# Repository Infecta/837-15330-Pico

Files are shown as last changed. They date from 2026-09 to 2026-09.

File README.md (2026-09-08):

# slidrr-PSoC
An attempt at a recreation of the official CHUNITHM Ground Slider for home use.

This project aims to use the same hardware* and firmware of the real ground slider for a more accurate and _faithful_ recreation of CHUNITHM's ground slider input.

<sub>*Same PSoCs. LED driver, power management and other things are ignored.</sub>

**Why?**
---
It all started because I couldn't get a _thick_ (3mm) acrylic overlay working on my original [simpl-slidrr](https://github.com/infecta/simpl-slidrr) project simply due to the fact that the MPR121s perform badly on any overlay above 2mm in thickness.

With this project, since we are using the same PSoCs as the official ground slider it gives us the following benefits:

- As close as possible touch polling/scanning to match arcade
- Thick overlays work reliably (Tested with loose/unscrewed 3mm and 6mm briefly)
- No guesswork needed for psoc firmware

**What this project includes**
---
- KiCad Source Files for the PCB
- CAD Files for the case including the Fusion360 project
- Firmware for the RP2040 Zero

> [!WARNING]
>
> **Agentic AI usage disclosure**
>
> A huge chunk of the code was provided by an AI agent. This only applies to the firmware for the RP2040 Zero.
>
> You may experience weird issues, whacky edge cases that might happen.

**Hardware Architecture**
---
The main CY8C22345 communicates to the RP2040 through UART. The firmware will pass those commands transparently unless it's an LED packet in which case, will be parsed by the RP2040 itself to drive the LEDs   

To put it in simple terms, the main job of the RP2040 is a Serial to USB adapter*

<sub>_*If we just gloss over the fact it also does air tower and IO4 emulation_</sub>

```mermaid
graph LR;
CY(Main CY8C22345)
PICO(RP2040)
LEDS(SK6812MINI-E Array)
Q{IS IT AN LED PACKET}

HOST --> PICO
PICO --> Q
Q --> |NO| CY
Q --> |YES|LED(Parse LED Data) --> LEDS

```
<sup>_Very simplified flowchart of what it does._</sup>

## Parts Needed (PCB)
<sub>All SMD components are 0603 unless stated otherwise</sub>
| Item | Quantity | Notes |
|-|-|-|
| CY8C22345 | 2 | [Link(Taobao)](https://item.taobao.com/item.htm?id=972956170652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). Same chips used as the official ground slider. Depending on where you are, these may be easier or harder to source. Must be an SSOP-28 package to fit on the PCB. If you found a different package you'll have modify the PCB. Get extras just in case things go wrong (bad chip, broken pins etc.)
| Arduino Pro Micro | 1 | A cheap (and slightly difficult) way to flash the PSoC with the ground slider firmware using [arduino_hssp](https://github.com/miracoli/arduino_hssp). **Make sure it's the 5V model**. **NOTE: You will need linux to use this with [psocdude](https://github.com/miracoli/psocdude)**. If you have another way of programming the PSoC like a MiniProg then go that route.
| WaveShare RP2040 Zero | 1 | Main brains (UART Passthrough, IO4, LED driver)
| [This](./guide-media/button.png) SMD tactile switch | 2 | I'm not sure what these are formally called. but I used these for the footprint on the PCB.
| SN74LV1T34DBVR Logic Level Shifter | 1 | This is for the SK6812MINI-E LED data pins (Needs 5V logic rather than 3.3V logic). You can substitute this with any other level shifter provided it's pin compatible or modify the PCB if you want to use a different one.
| SK6812MINI-E LEDs | 31 | LEDs.
| 4x DIP switch | 1 | Temporary but needed during flashing & troubleshooting. Mainly to connect both PSoC I<sup>2</sup>C lines and connect to the I<sup>2</sup>C pull-up resistors.
| JST XH5 Connectors | 2 | Optional. But nice to have to reliably flash PSoCs
| JST XH6 Connectors | 2 | For connecting air towers
| 100nf/0.1uF X5R Capacitors | 32 | Decoupling caps for level shifter and LEDs 
| 4.7uF X5R Capacitors | 4 | Decoupling caps for PSoCs
| 4.7nF X7R Capacitors | 2 | CapSense<sup>TM</sup> Modulator cap
| 560R/560ohm Resistors | 32 | Placed before the touch electrodes. Values are just an estimate and typical range I have tested.
| 1K Resistor | 1 | Part of a voltage divider to shift down the 5V UART signal to 3.3V going into the RP2040 Zero
| 2K Resistor | 1 | Part of a voltage divider to shift down the 5V UART signal to 3.3V going into the RP2040 Zero
| 3K - 4.7K Resistor | 2 | I<sup>2</sup>C pull-up resistors. Within this range should be fine.
| 330R/330ohm Resistor | 1 | Needed for the logic level shifter. Followed datasheet. If changing level shifter check datasheet for info.
| [whowechina chu_pico IR airs](https://github.com/whowechina/chu_pico) | 1 pair | IR tower code based around this design. Check chu_pico repo for more info. **IMPORTANT:** CURRENT LIMITING RESISTORS NEED TO BE CHANGED TO A HIGHER VALUE. CHECK BELOW.

## Notes

The chu_pico airs draw around ~878mA per emitter with 0.75ohm resistor (If we were to follow whowe's guide for the airs). Either due to the WaveShare RP2040 zero's 3v3 regulator or general power budget **it is too high** and UART will fail as there is not enough power to go around for the PSoCs and possibly the LEDs.

> [!WARNING]
>
> Using the airs as-is with the 0.75ohm resistors **may** burn out the 3v3 regulator as it can get **very** hot.
> 

I suggest using a 50ohm or 100ohm resistor instead. This drops the emitter amperage draw to about ~40mA and ~21mA respectively.
Peak for a single IR phase (2 IR Emitters) would be ~80mA and ~42mA respectively too, which is well within the budget

## Build _*"guide"*_

This doc fully assumes you are comfortable with soldering SMD components.

_Protip: Use the Interactive Html Bom plugin on KiCAD to easily figure out where all the components go._

### Ordering the PCB
---
We're using [JLCPCB](https://jlcpcb.com) for this guide.

You can leave everything on default but I recommend a black solder mask so that the lights look better

### Notes for the RP2040-Zero
---
I won't lie, I forgot why I even placed the footprint they way I did.
But the RP2040 chip is facing **upwards** so please keep that in mind.

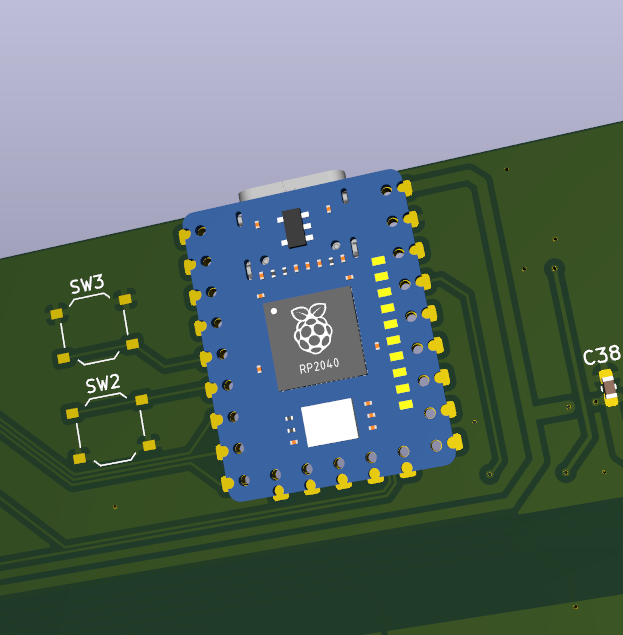
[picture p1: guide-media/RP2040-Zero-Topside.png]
RP2040 TopSide

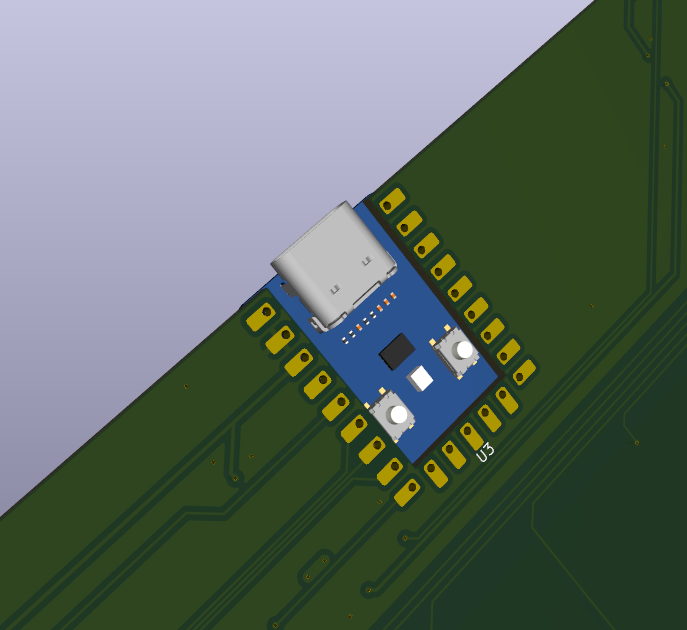
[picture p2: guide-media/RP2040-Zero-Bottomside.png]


### Flashing the firmware
---
**This section will assume you are doing the psocdude + arduino_hssp route.**

**This also assumes you have sourced your own dump of the offical 837-15330/Ground slider firmware**

**This section will not guide you on how to flash the arduino or compile psocdude. Use google or ask an LLM for guidance.**

Few things are needed to change in the `psocdude.conf` file in order to get it flashed.

Inside `psocdude.conf` find the `CY8C22345` line. It should look like this.
```bash
#------------------------------------------------------------
# CY8C22345
#------------------------------------------------------------

part
  id      = "CY8C22345";
  desc    = "CY8C22345";
  signature   = 0x00 0xD1;
  checksum_setup = CHECKSUM_SETUP_22_24_28_29_TST120_TMG120_TMA120;
  program_block = PROGRAM_BLOCK_21_22_23_24_28_29_TST_TMG_TMA;
  multi_bank = yes;
  memory "signature"
    size = 2;
  ;
;
```

Change it so it looks like this:
```bash
#------------------------------------------------------------
# CY8C22345
#------------------------------------------------------------

part
  id      = "CY8C22345";
  desc    = "CY8C22345";
  signature   = 0x00 0xD0;
  checksum_setup = CHECKSUM_SETUP_22_24_28_29_TST120_TMG120_TMA120;
  program_block = PROGRAM_BLOCK_21_22_23_24_28_29_TST_TMG_TMA;
  multi_bank = yes;
  memory "flash"
    paged     = yes;
    size      = 16384;
    page_size = 64;
    num_pages = 256;
    blocksize = 64;
    readsize  = 64;
  ;
  memory "signature"
    size = 2;
  ;
;
```

Flash the PSoC with:
```bash
psocdude -C psocdude.conf -p CY8C22345 -c arduino -P /dev/ttyACM0 -b 115200 -U flash:w:<DUMPED_FIRMWARE.bin/.hex>:r -F
```

#### Troubleshooting
---

**Scenario 1**

If your output looks like this:
```bash
Reading |                     | 0% 0.00spsocdude: ser_recv(): proggrammer is not responding
psocdude: error reading signature data for part "CY8C22345", rc=-1
psocdude: error reading signature data, rc=-1
```

It could be either one of 2 issues:

1. Unplug and replug your programmer, then try running the command again.

2. If that doesn't work check your solder connections.

**Scenario 2**

If your signature is 0xffff
1. Bad soldering.
2. Bad chip. (Unconfirmed)

I haven't figured out why this happens as of writing this. My only solution was switching out the chips with the extras I already had.

There might be more issues that I haven't experienced yet so I can't cover all bases.

### Case
---
TODO: CASE GUIDE HERE

## Credits

[whowechina](https://github.com/whowechina) - Air Code and PCB is heavily referenced and adapted for the firmware from the [chu_pico](https://github.com/whowechina/chu_pico) project.

[Cons&Stuff](https://consandstuff.github.io/) Discord Server - For guidance and troubleshooting of my project especially [somewhatlurker](https://github.com/somewhatlurker) for their insight of the slider protocol.

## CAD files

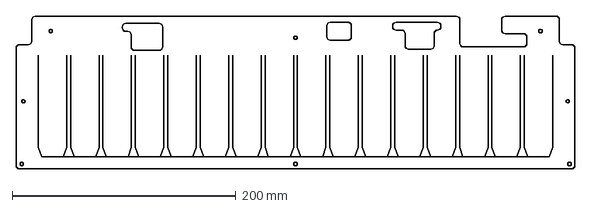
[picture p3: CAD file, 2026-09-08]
Case-files/chu-psoc-lgp-panel.dxf
500.0 x 136.5 mm

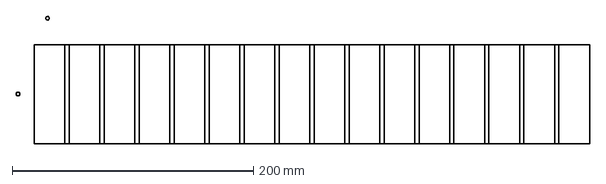
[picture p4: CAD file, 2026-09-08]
KiCAD-project-files/DXF/Isolated/Acrylic Light Guide.dxf
475.3 x 105.4 mm

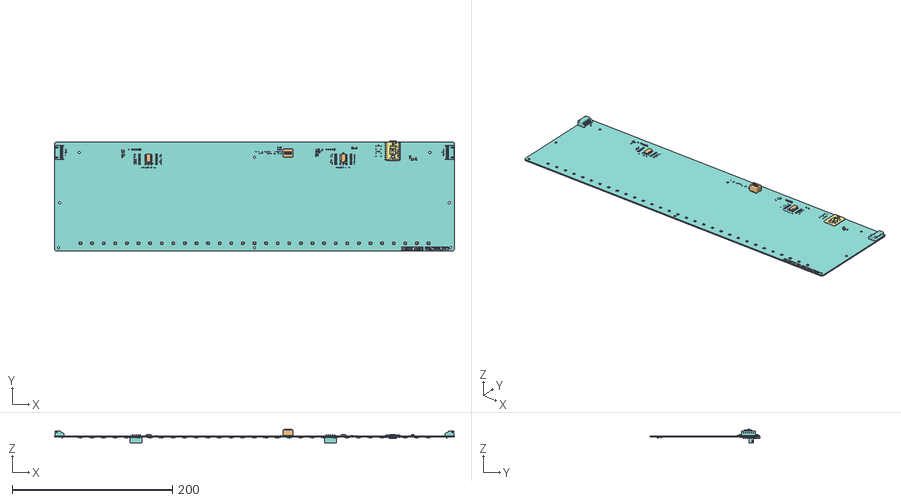
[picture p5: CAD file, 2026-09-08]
KiCAD-project-files/pcb-model/processed-23-08-2026 [1]/slidrr-cy8c.obj
500.0 x 137.7 x 17.3
obj1
obj2
obj3
obj4
obj5
obj6
obj7
obj8
obj9
obj10
obj11
obj12
obj13
obj14
obj15
obj16
obj17
obj18
obj19
obj20
obj21
obj22
obj23
obj24
obj25
obj26
obj27
obj28
obj29
obj30
obj31
obj32

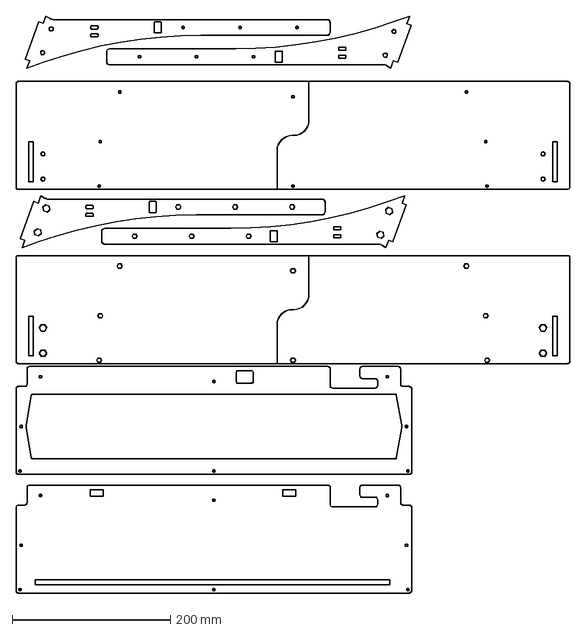
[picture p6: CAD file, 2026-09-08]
Case-files/chu-psoc-casepieces.dxf
700.0 x 729.2 mm

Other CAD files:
KiCAD-project-files/DXF/slidrr-cy8c.dxf
KiCAD-project-files/pcb-model/processed-23-08-2026 [2]/slidrr-cy8c.obj
KiCAD-project-files/pcb-model/processed-23-08-2026/slidrr-cy8c.obj
Case-files/slidrr-housing.f3d

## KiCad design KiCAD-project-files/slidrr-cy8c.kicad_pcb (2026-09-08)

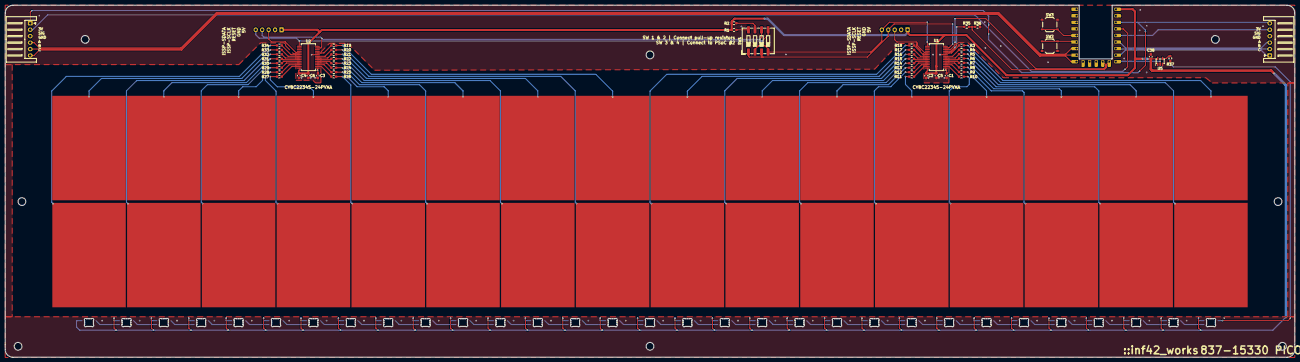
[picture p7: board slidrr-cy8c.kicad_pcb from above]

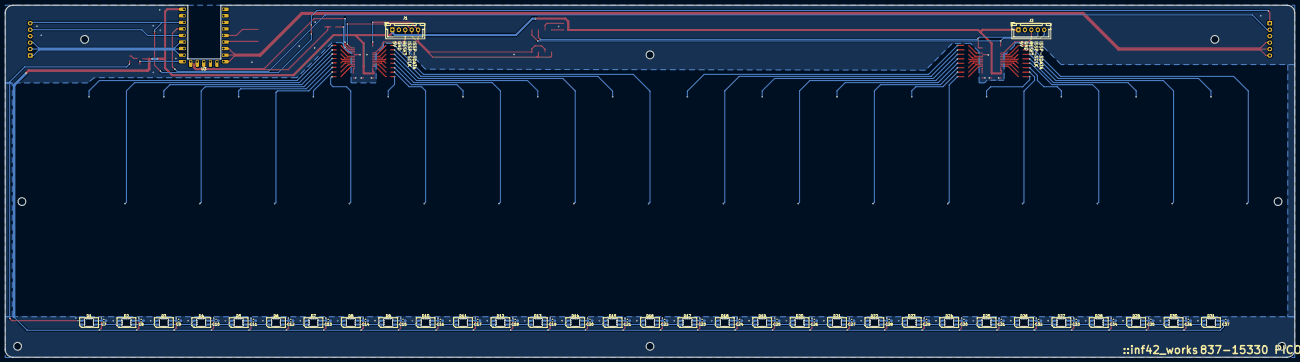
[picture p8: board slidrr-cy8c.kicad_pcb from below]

Board: 2 copper layers, 500.0 x 136.5 mm, 118 parts (65 on the bottom side), 123 nets.

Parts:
C1, C3: 4.7nF X7R; C_0603_1608Metric_Pad1.08x0.95mm_HandSolder
C2, C4, C5, C6: X5R 4.7uF 16V; C_0603_1608Metric_Pad1.08x0.95mm_HandSolder
C7, C8, C9, C10, C11, C12, C13, C14, C15, C16, C17, C18, C19, C20, C21, C22, C23, C24, C25, C26, C27, C28, C29, C30, C31, C32, C33, C34, C35, C36, C37, C38: 0.1uF; C_0603_1608Metric_Pad1.08x0.95mm_HandSolder
D1, D2, D3, D4, D5, D6, D7, D8, D9, D10, D11, D12, D13, D14, D15, D16, D17, D18, D19, D20, D21, D22, D23, D24, D25, D26, D27, D28, D29, D30, D31: SK6812MINI-E; LED_SK6812MINI-E_3.2x2.8mm_P1.5mm_ReverseMount
J1: ISSP U1; JST_XH_B5B-XH-A_1x05_P2.50mm_Vertical
J2: ISSP U2; JST_XH_B5B-XH-A_1x05_P2.50mm_Vertical
J3: Conn_01x32_Socket; slidrr-touchslider
J4, J5: JST-XH Series; JST_XH_S6B-XH-A_1x06_P2.50mm_Horizontal
R1, R2: 3.2K; R_0603_1608Metric_Pad0.98x0.95mm_HandSolder
R3, R4, R5, R6, R7, R8, R9, R10, R11, R12, R13, R14, R15, R16, R17, R18, R19, R20, R21, R22, R23, R24, R25, R26, R27, R28, R29, R30, R31, R32, R33, R34: R_Small; R_0603_1608Metric_Pad0.98x0.95mm_HandSolder
R35: 1K; R_0603_1608Metric_Pad0.98x0.95mm_HandSolder
R36: 2K; R_0603_1608Metric_Pad0.98x0.95mm_HandSolder
R37: 330R; R_0603_1608Metric_Pad0.98x0.95mm_HandSolder
SW1: SW_DIP_x04; SW_DIP_SPSTx04_Slide_9.78x12.34mm_W8.61mm_P2.54mm
SW2, SW3: SW_Push; SW_Push_1P1T_XKB_TS-1187A
U1, U2: SSOP-28_5.3x10.2mm_P0.65mm
U3: RP2040-Zero
U5: SN74LV1T34DBVR; SOT-23-5

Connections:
3V3: J4.1, J5.6, U3.20 (3V3)
3v3 LED DATA: U3.14 (GP14), U5.2 (A)
5V LED DATA: D1.2 (DIN), R37.2
+5V: C2.1, C4.1, C5.1, C6.1, C7.2, C8.2, C9.2, C10.2, C11.2, C12.2, C13.2, C14.2, C15.2, C16.2, C17.2, C18.2, C19.2, C20.2, C21.2, C22.2, C23.2, C24.2, C25.2, C26.2, C27.2, C28.2, C29.2, C30.2, C31.2, C32.2, C33.2, C34.2, C35.2, C36.2, C37.2, C38.2, D1.3 (VDD), D2.3 (VDD), D3.3 (VDD), D4.3 (VDD), D5.3 (VDD), D6.3 (VDD), D7.3 (VDD), D8.3 (VDD), D9.3 (VDD), D10.3 (VDD), D11.3 (VDD), D12.3 (VDD), D13.3 (VDD), D14.3 (VDD), D15.3 (VDD), D16.3 (VDD), D17.3 (VDD), D18.3 (VDD), D19.3 (VDD), D20.3 (VDD), D21.3 (VDD), D22.3 (VDD), D23.3 (VDD), D24.3 (VDD), D25.3 (VDD), D26.3 (VDD), D27.3 (VDD), D28.3 (VDD), D29.3 (VDD), D30.3 (VDD), D31.3 (VDD), J1.1, J2.1, R1.2, R2.2, U1.28 (Vdd), U2.28 (Vdd), U3.22 (5V), U5.5 (VCC)
AIR A L: J4.4, U3.6 (GP6)
AIR A R: J5.3, U3.17 (GP27)
AIR B L: J4.5, U3.7 (GP7)
AIR B R: J5.2, U3.16 (GP26)
AIR C L: J4.6, U3.8 (GP8)
AIR C R: J5.1, U3.15 (GP15)
AIR SIG L: J4.2, U3.19 (GP29)
AIR SIG R: J5.5, U3.18 (GP28)
GND: C1.1, C2.2, C3.1, C4.2, C5.2, C6.2, C7.1, C8.1, C9.1, C10.1, C11.1, C12.1, C13.1, C14.1, C15.1, C16.1, C17.1, C18.1, C19.1, C20.1, C21.1, C22.1, C23.1, C24.1, C25.1, C26.1, C27.1, C28.1, C29.1, C30.1, C31.1, C32.1, C33.1, C34.1, C35.1, C36.1, C37.1, C38.1, D1.1 (VSS), D2.1 (VSS), D3.1 (VSS), D4.1 (VSS), D5.1 (VSS), D6.1 (VSS), D7.1 (VSS), D8.1 (VSS), D9.1 (VSS), D10.1 (VSS), D11.1 (VSS), D12.1 (VSS), D13.1 (VSS), D14.1 (VSS), D15.1 (VSS), D16.1 (VSS), D17.1 (VSS), D18.1 (VSS), D19.1 (VSS), D20.1 (VSS), D21.1 (VSS), D22.1 (VSS), D23.1 (VSS), D24.1 (VSS), D25.1 (VSS), D26.1 (VSS), D27.1 (VSS), D28.1 (VSS), D29.1 (VSS), D30.1 (VSS), D31.1 (VSS), J1.2, J2.2, J4.3, J5.4, R36.2, SW2.2, SW3.2, U1.9 (Vss/GND), U1.14 (Vss/GND), U2.9 (Vss/GND), U2.14 (Vss/GND), U3.21 (GND), U5.3 (GND)
I2C_SCL_U1: J1.4, SW1.1, SW1.3, U1.13 (P1[1])
I2C_SCL_U2: J2.4, SW1.6, U2.13 (P1[1])
I2C_SDA_U1: J1.5, SW1.2, SW1.4, U1.15 (P1[0])
I2C_SDA_U2: J2.5, SW1.5, U2.15 (P1[0])
ISSP_RESET_U1: J1.3, U1.19 (XRES)
ISSP_RESET_U2: J2.3, U2.19 (XRES)
unnamed: D1.4 (DOUT), D2.2 (DIN)
unnamed: D2.4 (DOUT), D3.2 (DIN)
unnamed: D3.4 (DOUT), D4.2 (DIN)
unnamed: D4.4 (DOUT), D5.2 (DIN)
unnamed: D5.4 (DOUT), D6.2 (DIN)
unnamed: D6.4 (DOUT), D7.2 (DIN)
unnamed: D7.4 (DOUT), D8.2 (DIN)
unnamed: D8.4 (DOUT), D9.2 (DIN)
unnamed: D9.4 (DOUT), D10.2 (DIN)
unnamed: D10.4 (DOUT), D11.2 (DIN)
unnamed: D11.4 (DOUT), D12.2 (DIN)
unnamed: D12.4 (DOUT), D13.2 (DIN)
unnamed: D13.4 (DOUT), D14.2 (DIN)
unnamed: D14.4 (DOUT), D15.2 (DIN)
unnamed: D15.4 (DOUT), D16.2 (DIN)
unnamed: D16.4 (DOUT), D17.2 (DIN)
unnamed: D17.4 (DOUT), D18.2 (DIN)
unnamed: D18.4 (DOUT), D19.2 (DIN)
unnamed: D19.4 (DOUT), D20.2 (DIN)
unnamed: D20.4 (DOUT), D21.2 (DIN)
unnamed: D21.4 (DOUT), D22.2 (DIN)
unnamed: D22.4 (DOUT), D23.2 (DIN)
unnamed: D23.4 (DOUT), D24.2 (DIN)
unnamed: D24.4 (DOUT), D25.2 (DIN)
unnamed: D25.4 (DOUT), D26.2 (DIN)
unnamed: D26.4 (DOUT), D27.2 (DIN)
unnamed: D27.4 (DOUT), D28.2 (DIN)
unnamed: D28.4 (DOUT), D29.2 (DIN)
unnamed: D29.4 (DOUT), D30.2 (DIN)
unnamed: D30.4 (DOUT), D31.2 (DIN)
unnamed: J3.1, R3.1
unnamed: J3.2, R4.1
unnamed: J3.3, R5.1
unnamed: J3.4, R6.1
unnamed: J3.5, R7.1
unnamed: J3.6, R8.1
unnamed: J3.7, R9.1
unnamed: J3.8, R10.1
unnamed: J3.9, R11.1
unnamed: J3.10, R12.1
unnamed: J3.11, R13.1
unnamed: J3.12, R14.1
unnamed: J3.13, R15.1
unnamed: J3.14, R16.1
unnamed: J3.15, R17.1
unnamed: J3.16, R18.1
unnamed: J3.17, R19.1
unnamed: J3.18, R20.1
unnamed: J3.19, R21.1
unnamed: J3.20, R22.1
unnamed: J3.21, R23.1
unnamed: J3.22, R24.1
unnamed: J3.23, R25.1
unnamed: J3.24, R26.1
unnamed: J3.25, R27.1
unnamed: J3.26, R28.1
unnamed: J3.27, R29.1
unnamed: J3.28, R30.1
unnamed: J3.29, R31.1
unnamed: J3.30, R32.1
unnamed: J3.31, R33.1
unnamed: J3.32, R34.1
unnamed: R1.1, SW1.8
unnamed: R2.1, SW1.7
unnamed: C1.2, U1.1 (P0[7])
unnamed: C3.2, U2.1 (P0[7])
unnamed: R35.2, R36.1, U3.13 (GP13)
unnamed: R37.1, U5.4 (Y)
SERVICE: SW2.1, U3.5 (GP5)
TEST: SW3.1, U3.4 (GP4)
TOUCH 1: R3.2, U1.10 (P1[7])
TOUCH 2: R4.2, U1.8 (P2[1])
TOUCH 3: R5.2, U1.7 (P2[3])
TOUCH 4: R6.2, U1.6 (P2[5])
TOUCH 5: R7.2, U1.5 (P2[7])
TOUCH 6: R8.2, U1.4 (P0[1])
TOUCH 7: R9.2, U1.3 (P0[3])
TOUCH 8: R10.2, U1.2 (P0[5])
TOUCH 9: R11.2, U1.27 (P0[6])
TOUCH 10: R12.2, U1.26 (P0[4])
TOUCH 11: R13.2, U1.25 (P0[2])
TOUCH 12: R14.2, U1.24 (P0[0])
TOUCH 13: R15.2, U1.23 (P2[6])
TOUCH 14: R16.2, U1.22 (P2[4])
TOUCH 15: R17.2, U1.21 (P2[2])
TOUCH 16: R18.2, U1.20 (P2[0])
TOUCH 17: R19.2, U2.10 (P1[7])
TOUCH 18: R20.2, U2.8 (P2[1])
TOUCH 19: R21.2, U2.7 (P2[3])
TOUCH 20: R22.2, U2.6 (P2[5])
TOUCH 21: R23.2, U2.5 (P2[7])
TOUCH 22: R24.2, U2.4 (P0[1])
TOUCH 23: R25.2, U2.3 (P0[3])
TOUCH 24: R26.2, U2.2 (P0[5])
TOUCH 25: R27.2, U2.27 (P0[6])
TOUCH 26: R28.2, U2.26 (P0[4])
TOUCH 27: R29.2, U2.25 (P0[2])
TOUCH 28: R30.2, U2.24 (P0[0])
TOUCH 29: R31.2, U2.23 (P2[6])
TOUCH 30: R32.2, U2.22 (P2[4])
TOUCH 31: R33.2, U2.21 (P2[2])
TOUCH 32: R34.2, U2.20 (P2[0])
UART_RX_U1: U1.12 (P1[3]), U3.12 (GP12)
UART_TX_U1: R35.1, U1.11 (P1[5])

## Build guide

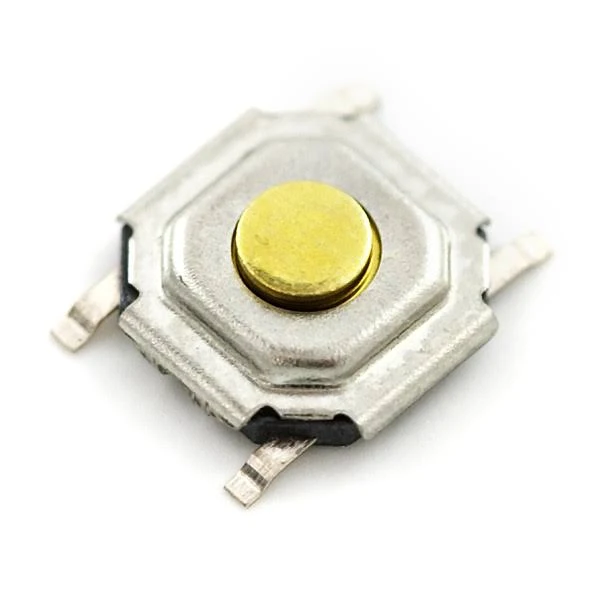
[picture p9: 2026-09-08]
guide-media/button.png

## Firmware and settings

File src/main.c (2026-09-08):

#include <string.h>
#include <stdio.h>
#include "bsp/board.h"
#include "hardware/gpio.h"
#include "pico/multicore.h"
#include "pico/stdlib.h"
#include "tusb.h"
#include "air.h"
#include "calibration.h"
#include "io4.h"
#include "led_driver.h"
#include "uart_bridge.h"
#include "usb_descriptors.h"

#define TEST_PIN 4
#define IO4_REPORT_INTERVAL_MS 4
#define AIR_DIAGNOSTIC_CDC 1
#define AIR_DIAGNOSTIC_INTERVAL_MS 100

static absolute_time_t next_io4_report;
static absolute_time_t next_air_diagnostic;

static io4_state_t io4_state;
static io4_input_report_t io4_report;

static void air_diagnostic_task(void) {
    if (!time_reached(next_air_diagnostic)) {
        return;
    }

    char line[64];
    const int length = snprintf(
        line,
        sizeof(line),
        "%u,%u,%u,%u,%u,%u\r\n",
        (unsigned)air_sensor_raw_value(IO4_AIR_LEFT_A),
        (unsigned)air_sensor_raw_value(IO4_AIR_RIGHT_A),
        (unsigned)air_sensor_raw_value(IO4_AIR_LEFT_B),
        (unsigned)air_sensor_raw_value(IO4_AIR_RIGHT_B),
        (unsigned)air_sensor_raw_value(IO4_AIR_LEFT_C),
        (unsigned)air_sensor_raw_value(IO4_AIR_RIGHT_C)
    );

    if (length <= 0 || (uint32_t)length > sizeof(line) ||
        tud_cdc_n_write_available(AIR_DIAGNOSTIC_CDC) < (uint32_t)length) {
        return;
    }

    (void)tud_cdc_n_write(AIR_DIAGNOSTIC_CDC, line, (uint32_t)length);
    (void)tud_cdc_n_write_flush(AIR_DIAGNOSTIC_CDC);
    next_air_diagnostic =
        make_timeout_time_ms(AIR_DIAGNOSTIC_INTERVAL_MS);
}

static bool calibration_requested(void) {
    gpio_init(TEST_PIN);
    gpio_set_dir(TEST_PIN, GPIO_IN);
    gpio_pull_up(TEST_PIN);

    if (gpio_get(TEST_PIN)) {
        return false;
    }

    sleep_ms(25);
    return !gpio_get(TEST_PIN);
}

static void show_colour_for(uint8_t red,
    uint8_t green,
    uint8_t blue,
    uint32_t duration_ms) {
    led_driver_set_solid(red, green, blue);

    absolute_time_t deadline =
        make_timeout_time_ms(duration_ms);

    while (!time_reached(deadline)) {
        led_driver_task();
        tight_loop_contents();
    }
}

int main(void) {
    uint16_t baselines[IO4_AIR_CHANNEL_COUNT];

    board_init();
    air_sensor_init();
    led_driver_init();

    if (calibration_requested()) {
        /*
         * Continuously scan for two seconds while the towers are clear.
         * This gives every phase repeated opportunities to stabilize.
         */
        led_driver_set_solid(255, 0, 0);
    
        absolute_time_t calibration_end =
            make_timeout_time_ms(2000);
    
        while (!time_reached(calibration_end)) {
            air_sensor_update();
            led_driver_task();
            tight_loop_contents();
        }
    
        if (air_sensor_capture_baselines(baselines) &&
            calibration_save(baselines)) {
            air_sensor_set_baselines(baselines);
    
            /* Green remains until game LED traffic replaces it. */
            led_driver_set_solid(0, 255, 0);
        }
    
        /*
         * Leave the display red when capture or flash saving fails.
         */
    } else if (calibration_load(baselines)) {
        air_sensor_set_baselines(baselines);
    }

    uart_bridge_init();
    io4_init( & io4_state);
    tusb_init();
    next_io4_report = get_absolute_time();
    next_air_diagnostic = get_absolute_time();

    // Flash operations are finished before this starts.
    multicore_launch_core1(air_sensor_core1_entry);

    while (true) {
        tud_task();

        uart_bridge_task();
        led_driver_task();
        air_diagnostic_task();

        io4_set_test_pressed( & io4_state, !gpio_get(TEST_PIN));

        io4_set_air_blocked( &
            io4_state,
            air_sensor_blocked_bitmap()
        );

        if (tud_hid_n_ready(0) && time_reached(next_io4_report)) {
            io4_build_input_report( & io4_state, & io4_report);

            tud_hid_n_report(
                0,
                IO4_REPORT_ID_INPUT, &
                io4_report,
                sizeof(io4_report)
            );

            next_io4_report =
                delayed_by_ms(next_io4_report, IO4_REPORT_INTERVAL_MS);
        }

        tight_loop_contents();
    }
}

uint16_t tud_hid_get_report_cb(uint8_t instance,
    uint8_t report_id,
    hid_report_type_t report_type,
    uint8_t * buffer,
    uint16_t requested_length) {
    (void) instance;

    if (report_id != IO4_REPORT_ID_INPUT ||
        report_type != HID_REPORT_TYPE_INPUT ||
        buffer == NULL) {
        return 0;
    }

    io4_build_input_report( & io4_state, & io4_report);

    uint16_t length = requested_length < sizeof(io4_report) ?
        requested_length :
        sizeof(io4_report);

    memcpy(buffer, & io4_report, length);
    return length;
}

void tud_hid_set_report_cb(uint8_t instance,
    uint8_t report_id,
    hid_report_type_t report_type,
    const uint8_t * buffer,
        uint16_t buffer_size) {
    (void) instance;

    if (report_type != HID_REPORT_TYPE_OUTPUT || buffer == NULL) {
        return;
    }

    const uint8_t * payload = buffer;
    uint16_t payload_size = buffer_size;

    if (report_id == 0) {
        if (buffer_size < 2 ||
            buffer[0] != IO4_REPORT_ID_OUTPUT) {
            return;
        }

        payload = & buffer[1];
        payload_size = buffer_size - 1;
    } else if (report_id != IO4_REPORT_ID_OUTPUT) {
        return;
    }

    io4_process_command( &
        io4_state,
        payload,
        payload_size
    );
}

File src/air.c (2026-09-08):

#include "air.h"

#include <stdbool.h>
#include <stdint.h>
#include <string.h>

#include "hardware/adc.h"
#include "hardware/gpio.h"
#include "pico/stdlib.h"

#define IR_PHASES 3

// ADC GPIO Assignments
// If you're changing this, change IR_SIGNAL_ADC too.
#define ADC_LEFT 29
#define ADC_RIGHT 28

// IR Phase Pin Assignments for each side
// Goes like { A, B, C }
static const uint8_t IR_LEFT_CHANNEL[IR_PHASES] = { 6, 7, 8 };

static const uint8_t IR_RIGHT_CHANNEL[IR_PHASES] = { 27, 26, 15 };

// ADC Pin Assignments
// GP29 = ADC3 = left signal
// GP28 = ADC2 = right signal
static const uint8_t IR_SIGNAL_ADC[2] = { 3, 2 };

static volatile uint16_t ir_raw[IO4_AIR_CHANNEL_COUNT];
static bool ir_blocked[IO4_AIR_CHANNEL_COUNT];

static uint16_t ir_baselines[IO4_AIR_CHANNEL_COUNT] = {
    3800, 3800,
    3800, 3800,
    3800, 3800,
};

static const uint8_t IR_TRIGGER_PERCENT = 17;

#define IR_DEBOUNCE_PERCENT 90

static uint8_t current_phase;
static volatile uint8_t published_bitmap;

static void emitters_off(void)
{
    for (uint8_t phase = 0; phase < IR_PHASES; ++phase) {
        gpio_put(IR_LEFT_CHANNEL[phase], false);
        gpio_put(IR_RIGHT_CHANNEL[phase], false);
    }
}

// Read IR Phases
// Since we are using 2 seperate pins instead of a unified one,
// We need to iterate through 2 pins at a time
static void ir_read(void)
{
    const uint8_t phase = current_phase;

    // IR Channel ON
    gpio_put(IR_LEFT_CHANNEL[phase], true);
    gpio_put(IR_RIGHT_CHANNEL[phase], true);

    sleep_us(10);

    // Read raw ADC value.
    // Every even number is the left side
    // Every odd number is the right side
    // {0, 1, 2, 3, 4, 5}
    for (uint8_t side = 0; side < 2; ++side) {
        adc_select_input(IR_SIGNAL_ADC[side]);
        sleep_us(2);

        ir_raw[(phase * 2) + side] = adc_read();
    }

    // IR Channel OFF
    gpio_put(IR_LEFT_CHANNEL[phase], false);
    gpio_put(IR_RIGHT_CHANNEL[phase], false);

    current_phase = (uint8_t)((phase + 1) % IR_PHASES);
}

// Only the agent and god knows what's happening here
// Maybe even only god now.
// Taken from my other firmware.. which is adapted from whowe's firmware.
static void ir_judge(void)
{
    uint8_t bitmap = 0;

    for (uint8_t channel = 0;
         channel < IO4_AIR_CHANNEL_COUNT;
         ++channel) {
        const int offset =
            (int)ir_baselines
        [channel] - (int)ir_raw[channel];

        int threshold =
            ((int)ir_baselines
        [channel] * IR_TRIGGER_PERCENT) / 100;

        if (ir_blocked[channel]) {
            threshold =
                (threshold * IR_DEBOUNCE_PERCENT) / 100;
        }

        ir_blocked[channel] = offset >= threshold;

        if (ir_blocked[channel]) {
            bitmap |= (uint8_t)(1 << channel);
        }
    }

    published_bitmap = bitmap;
}

// IR Tower Initialization
void air_sensor_init(void)
{
    for (uint8_t phase = 0; phase < IR_PHASES; ++phase) {
        gpio_init(IR_LEFT_CHANNEL[phase]);
        gpio_set_dir(IR_LEFT_CHANNEL[phase], GPIO_OUT);
        gpio_put(IR_LEFT_CHANNEL[phase], false);
        gpio_set_drive_strength(
            IR_LEFT_CHANNEL[phase],
            GPIO_DRIVE_STRENGTH_12MA
        );

        gpio_init(IR_RIGHT_CHANNEL[phase]);
        gpio_set_dir(IR_RIGHT_CHANNEL[phase], GPIO_OUT);
        gpio_put(IR_RIGHT_CHANNEL[phase], false);
        gpio_set_drive_strength(
            IR_RIGHT_CHANNEL[phase],
            GPIO_DRIVE_STRENGTH_12MA
        );
    }

    adc_init();

    adc_gpio_init(ADC_LEFT);
    adc_gpio_init(ADC_RIGHT);

    emitters_off();

    memset((void *)ir_raw, 0, sizeof(ir_raw));
    memset(ir_blocked, 0, sizeof(ir_blocked));

    current_phase = 0;
    published_bitmap = 0;
}

bool air_sensor_capture_baselines(
    uint16_t baselines[IO4_AIR_CHANNEL_COUNT])
{
    if (baselines == NULL) {
        return false;
    }

    for (uint8_t phase = 0; phase < IR_PHASES; ++phase) {
        ir_read();
    }

    for (uint8_t channel = 0;
         channel < IO4_AIR_CHANNEL_COUNT;
         ++channel) {
        baselines[channel] = ir_raw[channel];
    }

    emitters_off();
    return true;
}

void air_sensor_set_baselines(
    const uint16_t baselines[IO4_AIR_CHANNEL_COUNT])
{
    if (baselines == NULL) {
        return;
    }

    for (uint8_t channel = 0;
         channel < IO4_AIR_CHANNEL_COUNT;
         ++channel) {
        ir_baselines
    [channel] = baselines[channel];
        ir_blocked[channel] = false;
    }

    published_bitmap = 0;
}

uint8_t air_sensor_blocked_bitmap(void)
{
    return published_bitmap;
}

uint16_t air_sensor_raw_value(uint8_t channel)
{
    if (channel >= IO4_AIR_CHANNEL_COUNT) {
        return 0;
    }

    return ir_raw[channel];
}

void air_sensor_update(void)
{
    ir_read();
    ir_judge();
}

void air_sensor_core1_entry(void)
{
    while (true) {
        air_sensor_update();
    }
}

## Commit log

2026-09-08 Add missing pieces, update README
    [Acrylic Light Guide.dxf, chu-psoc-casepieces.dxf, chu-psoc-lgp-panel.dxf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]
2026-10-11 Edited PCB to fix floating UART issue. Added crappy WebUI for diagnosis
